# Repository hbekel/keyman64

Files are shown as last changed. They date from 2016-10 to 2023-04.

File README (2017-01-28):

Keyman64

Programmable C64 keyboard interceptor and hardware control system

The keyman64 is a programmable keyboard interceptor and hardware
control system for computers equipped with a simple 64-key matrix
keyboard.

It is installed between the keyboard and the computer, continually
scanning the keyboard matrix and relaying the keyboard state to the
computer using a crosspoint switch. To the computer, the crosspoint
switch matrix looks just like a physical keyboard, while the keyman64
gains the ability to intercept keystrokes and control the matrix seen
by the computer.

The keyman64 can be configured to intercept special key combinations
and invoke arbitrary sequences of commands to alter the state of
sixteen general purpose control lines provided on the board. These
lines can be used to control additional hardware instead of using
physical buttons or switches.

Additional features include the ability to send predefined keyboard
macros or to redefine the keyboard layout. Commands can also be sent
from a remote PC via USB, or send on simple serial wire interface,
allowing remote control from either a PC or another microcontroller or
similar device.

For some concrete examples of what the keyman64 can do, see the

http://www.henning-bekel.de/keyman64/#configuration-examples

Please refer to the project page http://www.henning-bekel.de/keyman64
for detailed documentation.

Copyright 2016 Henning Bekel <h.bekel@googlemail.com>

LICENSING

Hardware licenced under CERN OHL v.1.2, see ./hardware/LICENSE.txt
Software and firmware licenced under GNU GPLv3, see ./LICENSE

The software contains MIT licensed code from
https://github.com/arkku/ihex for reading Intel HEX files, Copyright
(c) 2013-2015 Kimmo Kulovesi, see ./intelhex/LICENSE

The firmware contains the V-USB Driver (https://www.obdev.at/vusb),
(C)2008 Objective Development GmbH.

Distributed in the ./bootloader directory is the USBasp bootloader,
(C)2013 Stephan Baerwolf (matrixstorm@gmx.de) and (C)2008 Objective
Development GmbH (https://www.obdev.at/vusb).

In compliance with the terms of the (identical) V-USB driver and
USBasp bootloader licenses (./firmware/usbdrv/License.txt and
./bootloader/License.txt), the entire project is published under

http://www.henning-bekel.de/keyman64

In addition, this distribution contains

- a circuit diagram in PDF format, see ./hardware/keyman64-schematics.pdf
- the full source code for the host software in ./firmware
- this README file
- references to https://www.obdev.at/vusb

The USB Product and Vendor IDs for the Keyman64 USB device have kindly
been provided by OpenMoko, Inc (http://openmoko.org).

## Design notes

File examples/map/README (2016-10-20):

These files demonstrate how to put a simple loader program before an
actual game in order to configure the mappings between additional
buttons connected to the keyman's control lines and the keys that
should be pressed when these button lines go low.

To build this example, make sure that the utilities petcat and c1541
that came with vice are on the path, then type make. This will create
disk.d64 containing a loader program and a game program.

The loader program first configures the keyman by sending the map
commands via the serial interface connected to the processors IO port,
as described on the "serial interface" section on the website.  In
this example, four additional buttons are connected to port b bits 1-4
and mapped to press the a, b, c or d keys.

The file main.asm contains the ml code necessary to send the map
commands over the serial interface. The code is contained in data
lines in loader.bas.

After configuring the keyman, the loader loads the file "game" and
runs it. The "game" is just a simple basic program scanning for and
reporting keypresses for the mapped keys.

How is this useful?

I'm currently testing a small internal board that will allow the
rerouting of the analog lines from the control ports. These lines are
usually connected to the SID and used to read mice or paddles. You can
control the board to either route these lines to the SID as usual, or
you can route them "somewhere else" instead. And this will allow using
joysticks with two additional buttons connected to the paddle lines
and routed to the keyman, where the button presses can be mapped to
key presses.

For example, you could play games like Turrican and configure the
additional button tp press space in order to detonate your bombs, or
ready and fire missiles in Elite using the joystick, where the buttons
can be mapped to the t and m keys.

Since the keymans mappings can be reconfigured by a program running on
the C64 via the serial interface, it becomes trivial to add the proper
configuration to existing games, either by using a simple loader like
the one in this example, or by linking some additional code in front
of it.

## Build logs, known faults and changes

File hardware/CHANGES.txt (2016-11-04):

Add detailed descriptions of modifications made to the original
documentation in this file.

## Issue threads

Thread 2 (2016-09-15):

Feature Request: Grouping individual control lines

c0zmo, 2016-09-15:
Grouping individual control lines

In the current software, consecutive control lines can be tempered with as a n-bit-value using commands like 'increment port a bits 0-3' or 'clear port b bits 6-7'. However, there are situations where it would be very useful if individual lines on both ports could be grouped together to perform as above, i.e. when using a ribbon cable to connect the control lines. My suggestion is the implementation of a 'GROUP' command.

Examples:
GROUP RepromCharset=port a bit 0, port b bit 0
GROUP RepromKernal=port a bit 1, port b bit 1
GROUP MixSID=port a bit 6, port a bit 7

Now the Charset and Kernal could be changed with:
C: INCREASE RepromCharset
K: INCREASE RepromKernal

hbekel, 2016-09-15:
As for the suggestion itself, this will require some work under hood, since neither the configuration format nor the code dealing with bit ranges is prepared for this. I will have to look into it.

However, I don't think a dedicated GROUP directive is required, since the same can be achieved with user defined symbols, as in

```
RepromCharset = port a bit 0, port b bit 0

C: increase RepromCharset
```

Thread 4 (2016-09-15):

Feature Request: Configuration Terminal

c0zmo, 2016-09-15:
Configuration Terminal

Let the Keyman64 be programmable from the C64 alone by implementing a console-like command interface that uses the BASIC prompt as a terminal.

You could list the current confuration, alter control lines directly or even program new macros.

Mock-Up example:

READY.      <meta+F7> issues 'CONSOLE'-command
KEYMAN64 VERSION x.x BY HENNING
TYPE '?' FOR HELP.
> SHOW CONFIG <RETURN>
C: INCREASE PORT A BITS 0-1
K: INCREASE PORT A BITS 2-3
R: EXEC $FA

$FA: CLEAR PORT B BIT 7
$FA: SLEEP 20
$FA: TRISTATE PORT B BIT 7

> SHOW PORTS
    0 1 2 3 4 5 6 7
A: C C T T T T T T
B: T T S T C C C C

> TRISTATE PORT A BIT 0
B: T C T T T T T T

hbekel, 2016-09-15:
I like the idea of a shell, and I have been thinking about that, too. However, being able to enter plain text commands using the same syntax as in the configuration file would mean having to move the parser code into the Atmel as well. Not sure if that will be practical or whether it will still fit. Do you have any practical use cases for this?

And listing the current configuration in plain text would mean to also move the code that converts back from binary to configuration file syntax to the Atmel.

While this would probably be a neat feature, I'm not convinced that it justifies the effort.

c0zmo, 2016-09-15:
Well, the practical use would be independecy of a PC to check the config or perform changes :) However, you could start with a more or less "raw" dump of the config and the possibility to directly manipulate single control lines like in my example above.

Ultimately, I believe this would put Keyman64 onto a new level. Just consider how feasible it is just to install the proper USB-drivers under Windows. :(

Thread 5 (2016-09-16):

5V Power Connector for supplying other hardware

c0zmo, 2016-09-16:
What do you think about a power connector where one can drive i.e. the Overlay64 without having to draw power from the motherboard? It could be placed next to the serial interface and the USB socket.

hbekel, 2016-09-20:
Yes, that's a good idea. I'll might as well add a few while I'm at it if I find enough space.

hbekel, 2017-04-26:
It turns out this is a bad idea after all, especially when trying to supply power and ground to the Overlay64 from the keyman64 and when also using a long cable from the mainboard keyboard connector to the keyman64. The cable will create a long ground return path which lifts the ground at the Overlay in relation to the video signal and will prevent the overlay's LM1881 from properly detecting sync, especially with dark screen contents. The overlay's GND should be connected as close as possible to the video signal output.

Thus, no other device should probably be powered from the keyman just because "it's there already".

Closed 2017-04-26.

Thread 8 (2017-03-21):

Power-On-Keypress-Detection

c0zmo, 2017-03-21:
When a definable key is held down while powering up the unit, an alternative init-config is executed instead of (or following the) default one at the beginning of the config. The user could select which Kernal to use, mount a certain disk-image on the 1541U etc.

hbekel, 2017-04-19:
I think it will be easier and cleaner to implement a certain key to execute a command sequence bound to a non-key-slot instead of using different startup sections. I will look into this, thanks for the suggestion :)

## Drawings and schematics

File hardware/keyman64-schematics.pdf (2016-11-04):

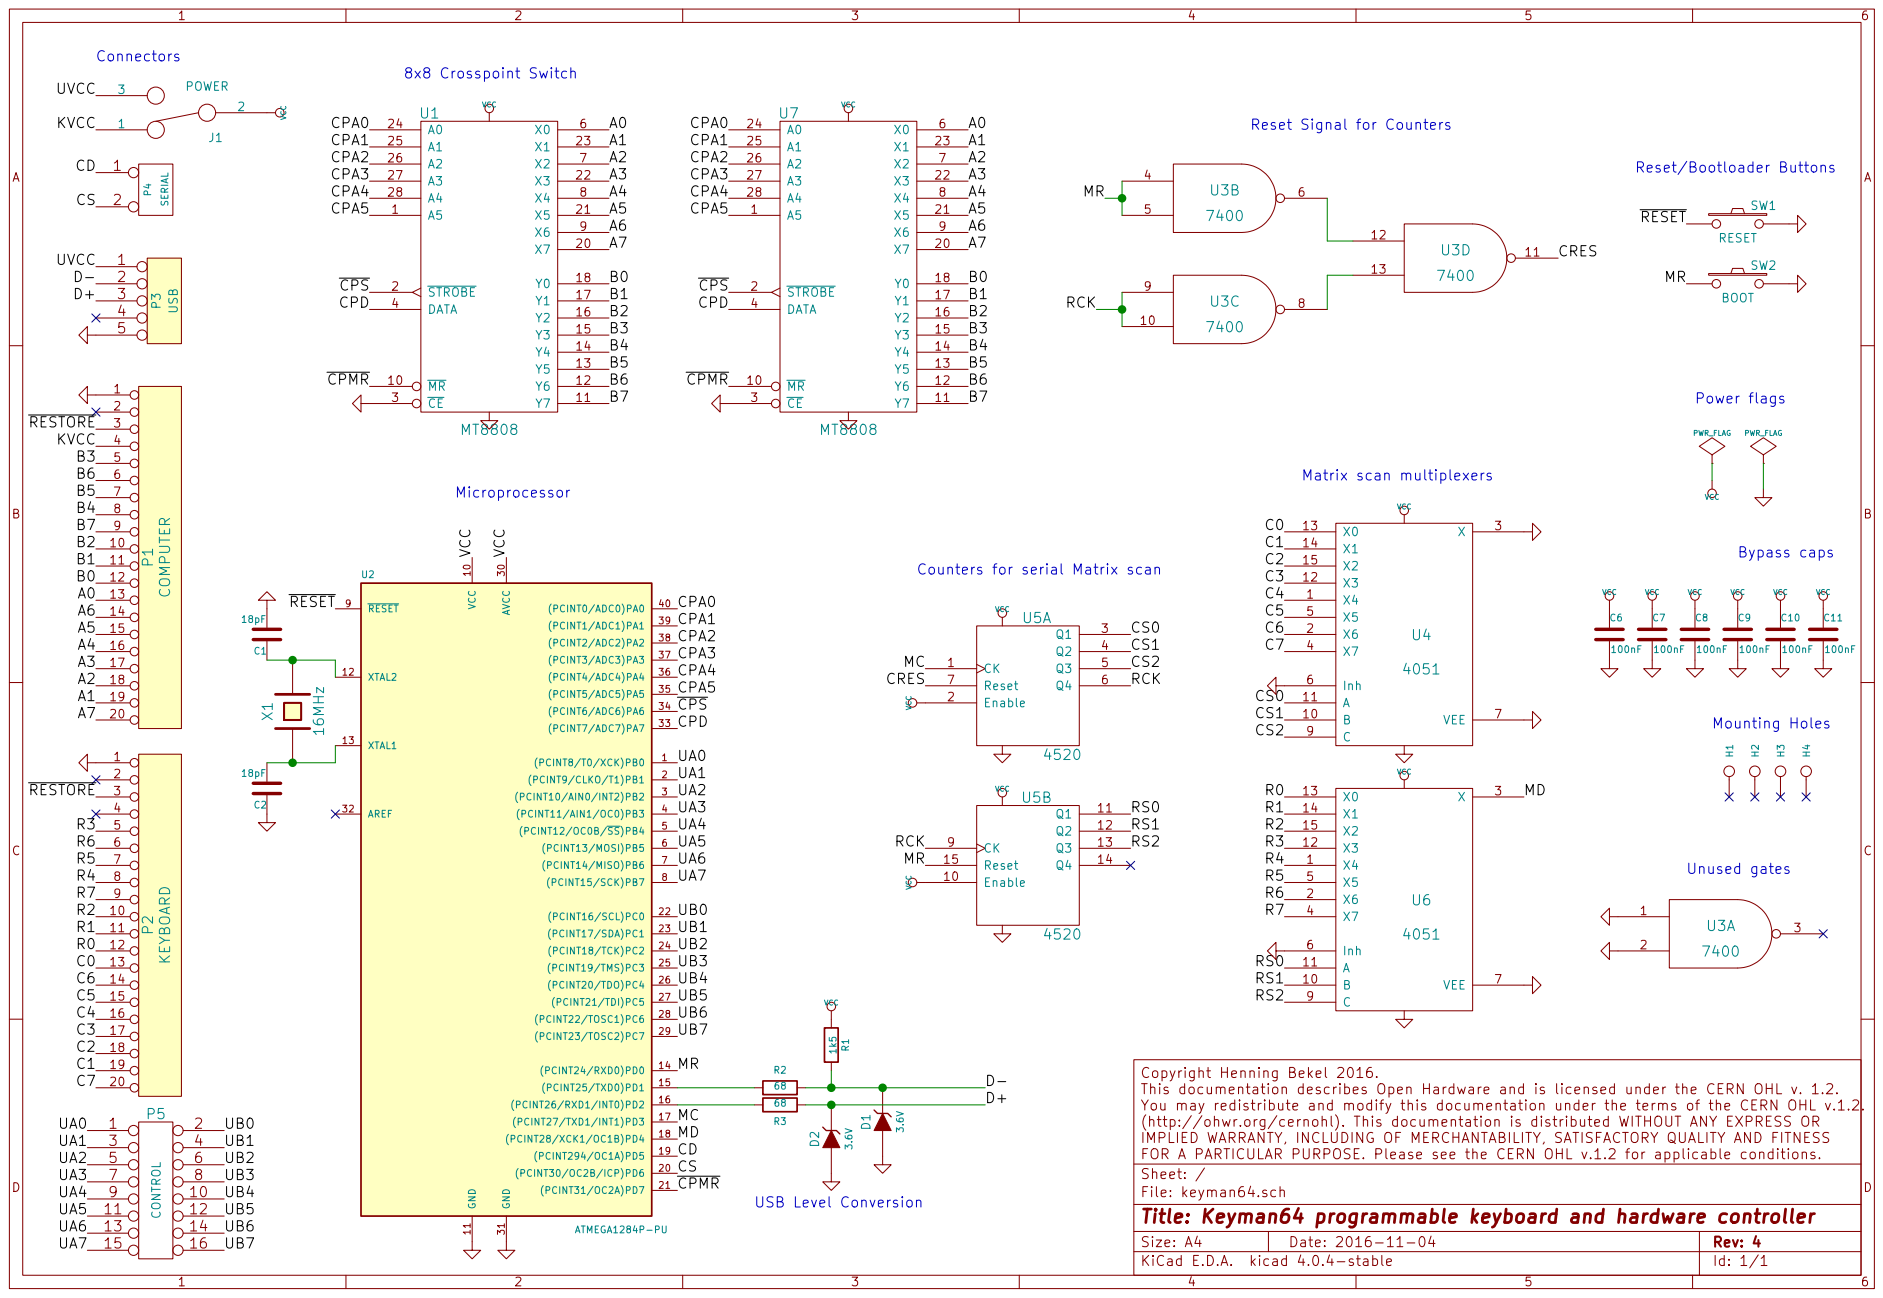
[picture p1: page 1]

Reset Signal for Counters

Bypass caps VCC VCC
Counters for serial Matrix scan

VCC USB Level Conversion

Id: 1/1 Title: Keyman64 programmable keyboard and hardware controller

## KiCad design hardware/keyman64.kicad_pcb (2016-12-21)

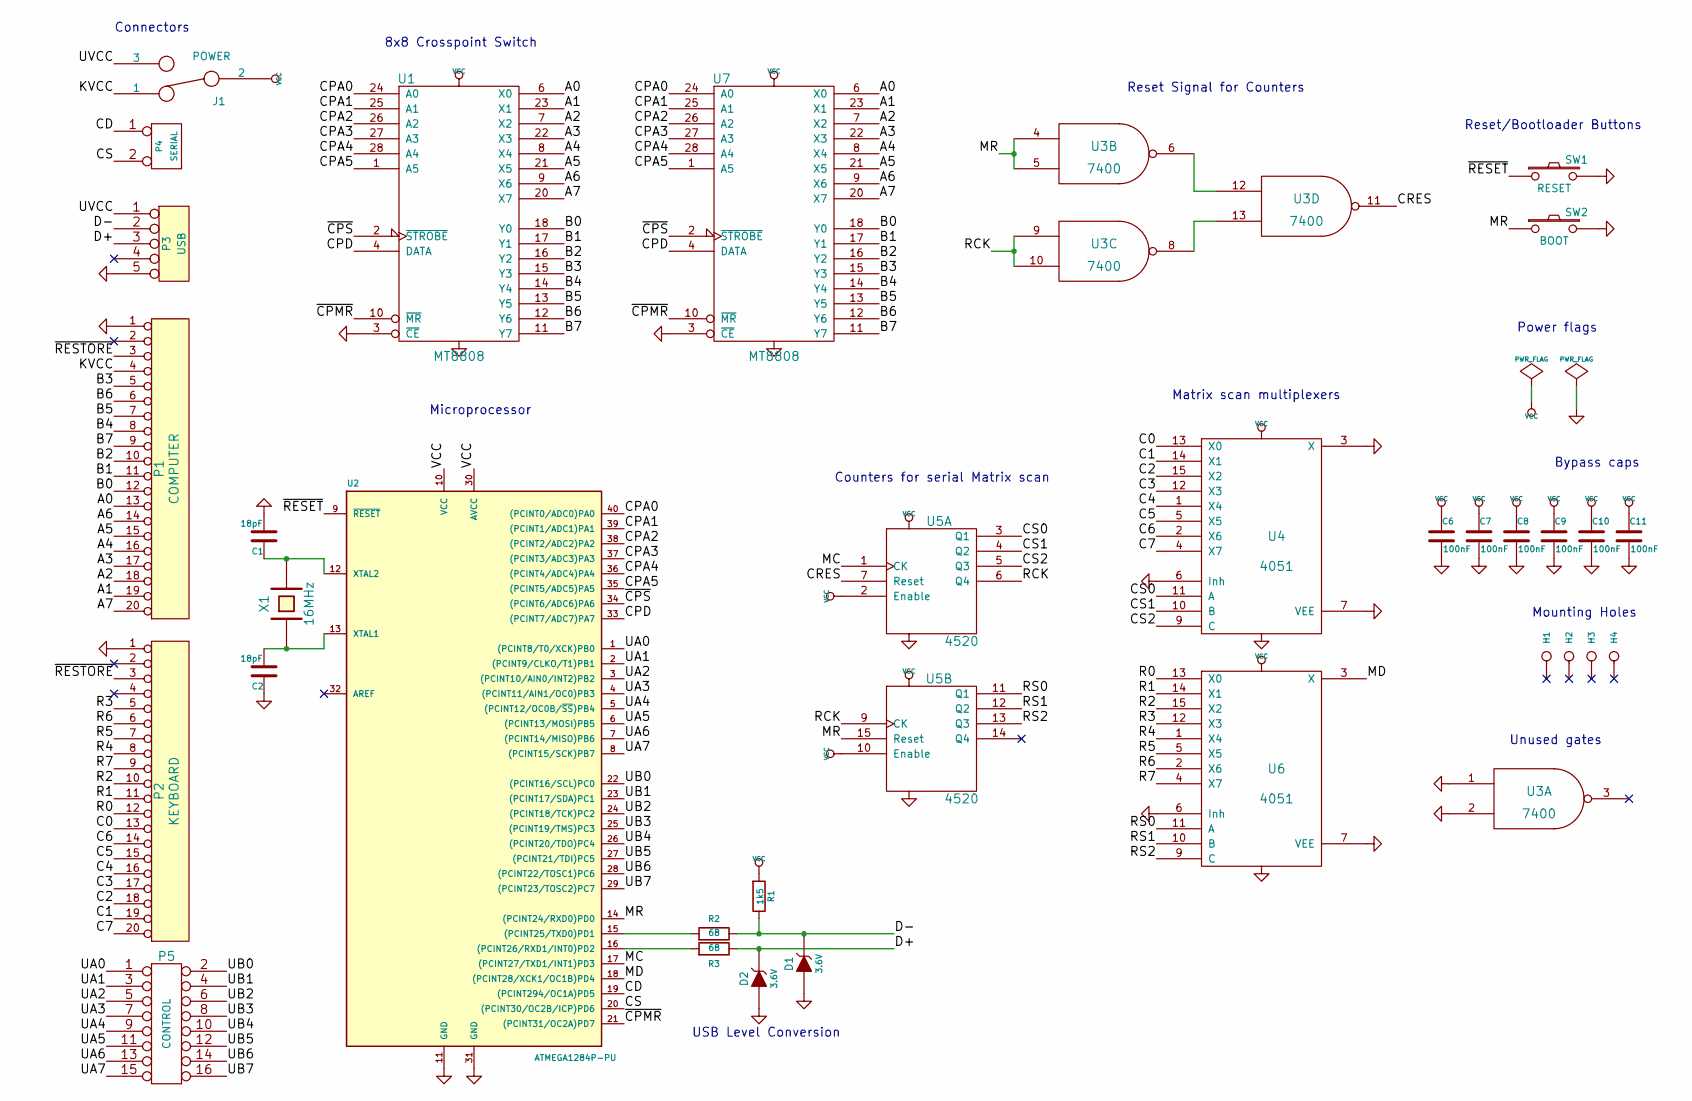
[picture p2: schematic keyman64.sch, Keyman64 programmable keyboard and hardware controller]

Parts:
C1, C2: 18pF; C_Disc_D3_P2.5
C6, C7, C8, C9, C10, C11: 100nF; C_Disc_D3_P2.5
D1, D2: 3.6V; D3
H1, H2, H3, H4: CONN_1; MountingHole_4mm
J1: POWER; pinHeader-3x1
P1: COMPUTER; pinHeader-20x1
P2: KEYBOARD; pinHeader-20x1
P3: USB; USB-MINI-B-H
P4: SERIAL; pinHeader-2x1
P5: CONTROL; pin_array_8x2
R1: 1k5; R3
R2, R3: 68; R3
SW1: RESET; Button
SW2: BOOT; Button
U1: MT8808; DIP-28__600
U2: ATMEGA1284P-PU; DIP-40__600
U3: 7400; DIP-14__300
U4, U6: 4051; DIP-16__300
U5: 4520; DIP-16__300
U7: MT8808; PLCC28
X1: 16MHz; HC-49V

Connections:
/A0: P1.13, U1.6 (X0), U7.6 (X0)
/A1: P1.19, U1.23 (X1), U7.23 (X1)
/A2: P1.18, U1.7 (X2), U7.7 (X2)
/A3: P1.17, U1.22 (X3), U7.22 (X3)
/A4: P1.16, U1.8 (X4), U7.8 (X4)
/A5: P1.15, U1.21 (X5), U7.21 (X5)
/A6: P1.14, U1.9 (X6), U7.9 (X6)
/A7: P1.20, U1.20 (X7), U7.20 (X7)
/B0: P1.12, U1.18 (Y0), U7.18 (Y0)
/B1: P1.11, U1.17 (Y1), U7.17 (Y1)
/B2: P1.10, U1.16 (Y2), U7.16 (Y2)
/B3: P1.5, U1.15 (Y3), U7.15 (Y3)
/B4: P1.8, U1.14 (Y4), U7.14 (Y4)
/B5: P1.7, U1.13 (Y5), U7.13 (Y5)
/B6: P1.6, U1.12 (Y6), U7.12 (Y6)
/B7: P1.9, U1.11 (Y7), U7.11 (Y7)
/C0: P2.13, U4.13 (X0)
/C1: P2.19, U4.14 (X1)
/C2: P2.18, U4.15 (X2)
/C3: P2.17, U4.12 (X3)
/C4: P2.16, U4.1 (X4)
/C5: P2.15, U4.5 (X5)
/C6: P2.14, U4.2 (X6)
/C7: P2.20, U4.4 (X7)
/CD: P4.1, U2.19 ((PCINT294/OC1A)PD5)
/CPA0: U1.24 (A0), U2.40 ((PCINT0/ADC0)PA0), U7.24 (A0)
/CPA1: U1.25 (A1), U2.39 ((PCINT1/ADC1)PA1), U7.25 (A1)
/CPA2: U1.26 (A2), U2.38 ((PCINT2/ADC2)PA2), U7.26 (A2)
/CPA3: U1.27 (A3), U2.37 ((PCINT3/ADC3)PA3), U7.27 (A3)
/CPA4: U1.28 (A4), U2.36 ((PCINT4/ADC4)PA4), U7.28 (A4)
/CPA5: U1.1 (A5), U2.35 ((PCINT5/ADC5)PA5), U7.1 (A5)
/CPD: U1.4 (DATA), U2.33 ((PCINT7/ADC7)PA7), U7.4 (DATA)
/CRES: U3.11, U5.7 (Reset)
/CS: P4.2 (PM), U2.20 ((PCINT30/OC2B/ICP)PD6)
/CS0: U4.11 (A), U5.3 (Q1)
/CS1: U4.10 (B), U5.4 (Q2)
/CS2: U4.9 (C), U5.5 (Q3)
/D+: D2.1 (K), P3.3, R3.1
/D-: D1.1 (K), P3.2, R1.1, R2.1
/KVCC: J1.1, P1.4
/MC: U2.17 ((PCINT27/TXD1/INT1)PD3), U5.1 (CK)
/MD: U2.18 ((PCINT28/XCK1/OC1B)PD4), U6.3 (X)
/MR: SW2.1, U2.14 ((PCINT24/RXD0)PD0), U3.4, U3.5, U5.15 (Reset)
/R0: P2.12, U6.13 (X0)
/R1: P2.11, U6.14 (X1)
/R2: P2.10, U6.15 (X2)
/R3: P2.5, U6.12 (X3)
/R4: P2.8, U6.1 (X4)
/R5: P2.7, U6.5 (X5)
/R6: P2.6, U6.2 (X6)
/R7: P2.9, U6.4 (X7)
/RCK: U3.9, U3.10, U5.6 (Q4), U5.9 (CK)
/RS0: U5.11 (Q1), U6.11 (A)
/RS1: U5.12 (Q2), U6.10 (B)
/RS2: U5.13 (Q3), U6.9 (C)
/UA0: P5.1, U2.1 ((PCINT8/T0/XCK)PB0)
/UA1: P5.3, U2.2 ((PCINT9/CLKO/T1)PB1)
/UA2: P5.5, U2.3 ((PCINT10/AIN0/INT2)PB2)
/UA3: P5.7, U2.4 ((PCINT11/AIN1/OC0)PB3)
/UA4: P5.9, U2.5 ((PCINT12/OC0B/~SS~)PB4)
/UA5: P5.11, U2.6 ((PCINT13/MOSI)PB5)
/UA6: P5.13, U2.7 ((PCINT14/MISO)PB6)
/UA7: P5.15, U2.8 ((PCINT15/SCK)PB7)
/UB0: P5.2, U2.22 ((PCINT16/SCL)PC0)
/UB1: P5.4, U2.23 ((PCINT17/SDA)PC1)
/UB2: P5.6, U2.24 ((PCINT18/TCK)PC2)
/UB3: P5.8, U2.25 ((PCINT19/TMS)PC3)
/UB4: P5.10, U2.26 ((PCINT20/TDO)PC4)
/UB5: P5.12, U2.27 ((PCINT21/TDI)PC5)
/UB6: P5.14, U2.28 ((PCINT22/TOSC1)PC6)
/UB7: P5.16, U2.29 ((PCINT23/TOSC2)PC7)
/UVCC: J1.3, P3.1
/~CPMR: U1.10 (~MR), U2.21 ((PCINT31/OC2A)PD7), U7.10 (~MR)
/~CPS: U1.2 (~STROBE), U2.34 ((PCINT6/ADC6)PA6), U7.2 (~STROBE)
/~RESET: SW1.1, U2.9 (~RESET)
/~RESTORE: P1.3, P2.3
GND: C1.2, C2.1, C6.2, C7.2, C8.2, C9.2, C10.2, C11.2, D1.2 (A), D2.2 (A), P1.1, P2.1, P3.5, SW1.2, SW2.2, U1.3 (~CE), U1.5 (VSS), U2.11 (GND), U2.31 (GND), U3.1, U3.2, U3.7 (GND), U4.3 (X), U4.6 (Inh), U4.7 (VEE), U4.8 (VSS), U5.8 (VSS), U6.6 (Inh), U6.7 (VEE), U6.8 (VSS), U7.3 (~CE), U7.5 (VSS)
unnamed: C1.1, U2.12 (XTAL2), X1.2
unnamed: C2.2, U2.13 (XTAL1), X1.1
unnamed: R2.2, U2.15 ((PCINT25/TXD0)PD1)
unnamed: R3.2, U2.16 ((PCINT26/RXD1/INT0)PD2)
unnamed: U3.6, U3.12
unnamed: U3.8, U3.13
VCC: C6.1, C7.1, C8.1, C9.1, C10.1, C11.1, J1.2, R1.2, U1.19 (VDD), U2.10 (VCC), U2.30 (AVCC), U3.14 (VCC), U4.16 (VDD), U5.2 (Enable), U5.10 (Enable), U5.16 (VDD), U6.16 (VDD), U7.19 (VDD)

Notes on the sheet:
USB Level Conversion
8x8 Crosspoint Switch
Reset Signal for Counters
Connectors
Counters for serial Matrix scan
Matrix scan multiplexers
Reset/Bootloader Buttons
Microprocessor
Unused gates
Power flags
Bypass caps
Mounting Holes

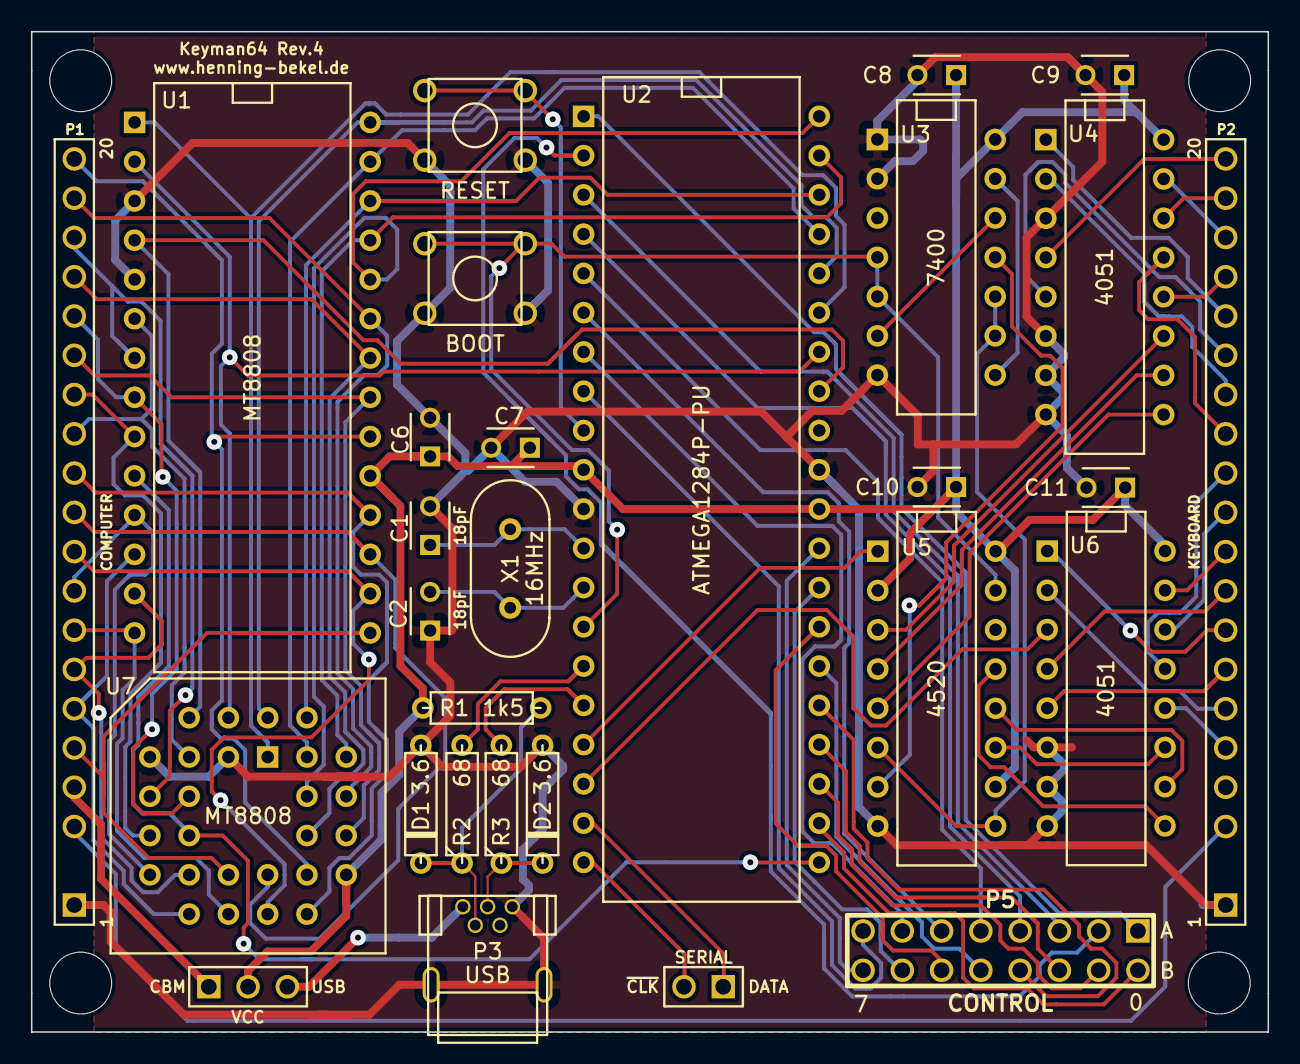
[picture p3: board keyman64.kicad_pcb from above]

Board: 2 copper layers, 80.0 x 64.7 mm, 33 parts (0 on the bottom side), 84 nets.

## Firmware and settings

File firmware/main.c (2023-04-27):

#include <stdint.h>
#include <stdbool.h>
#include <stdio.h>
#include <stdlib.h>
#include <ctype.h>
#include <avr/io.h>
#include <avr/wdt.h>
#include <avr/power.h>
#include <avr/interrupt.h>
#include <avr/eeprom.h>
#include <util/delay.h>

#include "main.h"
#include "encoding.h"
#include "../protocol.h"

uint8_t MC = 1<<PD3; // Matrix Clock
uint8_t MD = 1<<PD4; // Matrix Data
uint8_t MR = 1<<PD0; // Matrix Counter Reset

uint8_t CPS = 1<<PA6; // Crosspoint Strobe
uint8_t CPD = 1<<PA7; // Crosspoint Data
uint8_t CPR = 1<<PD7; // Crosspoint Reset

uint8_t CLK   = 1<<PD6; // Serial Clock (active low)
uint8_t DATA  = 1<<PD5; // Serial Data

#define STATE_RELAY   0x00
#define STATE_COMMAND 0x01
#define STATE_LOCKED  0x02
volatile uint8_t STATE = STATE_RELAY;

#define DEBOUNCE  _delay_ms(20)
#define DELAY     _delay_ms(20)
#define PROPAGATE _delay_ms(1)
#define WITHOUT_DELAY 0

volatile bool matrix[64];
volatile uint8_t locked[64];
volatile uint8_t layout[64];

Storage* storage;
State* transient;

volatile Serial serial;
volatile Mapping mappings[16];
volatile Config* config;
volatile uint8_t meta;
volatile bool boot;
volatile bool reset;

static void (*SetupCrosspointSwitch)(void);
static void (*ResetCrosspointSwitch)(void);
static void (*StrobeCrosspointSwitch)(void);
static void (*ClockMatrix)(void);

static volatile uint8_t usbCommand;
static volatile uint16_t usbDataReceived;
static volatile uint16_t usbDataLength;
static volatile uint8_t *usbData;
static volatile uint16_t usbDataPos;
static volatile uint16_t usbDelay;

int usbDescriptorStringSerialNumber[] = {
  USB_STRING_DESCRIPTOR_HEADER(16),
  0, 0, 0, 0, 0, 0, 0, 0,
  0, 0, 0, 0, 0, 0, 0, 0,
};

//-----------------------------------------------------------------------------

#include "config.h"
#include "../config.c"

//-----------------------------------------------------------------------------

void SetSerial(char *serial) {
  int len = strlen(serial);
  len = (len > 16) ? 16 : len;

  usbDescriptorStringSerialNumber[1] = (int) strlen(serial);

  for(uint8_t i=0; i<16; i++) {
    usbDescriptorStringSerialNumber[i+1] = (int) ((i < len) ? serial[i] : 0);
  }
}

//-----------------------------------------------------------------------------

void EnterBootloader(void) {
  storage->bootflag = BOOTLOADER_MAGIC;
  Storage_save_bootflag(storage);
  Reset();
}

void Reset(void) {
  cli();
  wdt_enable(WDTO_250MS);
  for(;;);
}

//-----------------------------------------------------------------------------

void SetupHardware(void) {

  wdt_disable();

  // Crosspoint Control
  DDRA  = 0b11111111;
  PORTA = 0b11000000;

  // USB, Bootloader, Matrix, Serial interface
  DDRD  = 0b10001001;
  PORTD = 0b11110000;

  SetupSerial();
}

//-----------------------------------------------------------------------------

void SetupSerial(void) {
  ResetSerial();

  PCMSK3 = CLK;
  PCICR |= (1<<PCIE3);
  sei();
}

//-----------------------------------------------------------------------------

void ResetSerial(void) {
  ExpectNextSerialByte();
  serial.command      = 0;
  serial.arguments[0] = 0;
  serial.arguments[1] = 0;
  serial.index        = 0;
}

//-----------------------------------------------------------------------------

void ExpectNextSerialByte() {
  serial.bit  = 1;
  serial.byte = 0;
}

//-----------------------------------------------------------------------------

void ExecuteSerialCommand() {

  uint8_t port;
  uint8_t mask;
  uint8_t key;
  Command *command;

  switch(serial.command) {

  case SERIAL_COMMAND_EXECUTE:
    ExecuteKey(serial.arguments[0]);
    break;

  case SERIAL_COMMAND_KEY_DOWN:
    SetCrosspointSwitchLocked(serial.arguments[0], true, LOCK_SERIAL);
    PROPAGATE;
    break;

  case SERIAL_COMMAND_KEY_UP:
    SetCrosspointSwitchLocked(serial.arguments[0], false, LOCK_SERIAL);
    PROPAGATE;
    break;

  case SERIAL_COMMAND_KEY_PRESS:
    RelayKeyPress(serial.arguments[0]);
    break;

  case SERIAL_COMMAND_MAP:

    port = ((serial.arguments[1] & 0x8) == 0) ? 0 : 1;
    mask = 1<<(serial.arguments[1] & 0x7);
    key = serial.arguments[0];

    Map(port, mask, key);

  case SERIAL_COMMAND_SET:
    command = Command_new();
    command->port = serial.arguments[1] >> 3;
    command->mask = 1<<(serial.arguments[1] & 0x07);
    command->data = serial.arguments[0];

    switch(command->data) {
    case 0 : command->action = ACTION_CLEAR;    break;
    case 1 : command->action = ACTION_SET;      break;
    case 2 : command->action = ACTION_TRISTATE; break;
    default: command->action = ACTION_NONE;     break;
    }

    ExecuteCommand(config, command);
    break;

  case SERIAL_COMMAND_TYPE:
    chrout(serial.arguments[0]);
    break;
  }
}

//-----------------------------------------------------------------------------

ISR(PCINT3_vect) {

  if((PIND & CLK) != 0) return;

  if((PIND & DATA) != 0) {
    serial.byte |= serial.bit;
  }
  serial.bit = serial.bit << 1;

  if(serial.bit == 0) { // byte complete

    if(serial.index == 0) { // received command
      serial.command = serial.byte;
      serial.index = SERIAL_COMMAND_ARITY_FOR[serial.command];
    }
    else { // received argument
      serial.arguments[--serial.index] = serial.byte;
    }

    if(serial.index == 0) { // all arguments received
      ExecuteSerialCommand();
      ResetSerial();
    }
    else {
      ExpectNextSerialByte();
    }
  }
}

//-----------------------------------------------------------------------------

void SetupMappings(void) {
  for(uint8_t i=0; i<16; i++) {
    mappings[i].pins = NULL;
  }
}

//-----------------------------------------------------------------------------

static uint8_t mask2bitnum(uint8_t mask) {
  for(uint8_t i = 0; i<8; i++) {
    if(mask & (1<<i)) return i;
  }
  return 0;
}

//-----------------------------------------------------------------------------

void Map(uint8_t p, uint8_t mask, uint8_t key) {

  uint8_t volatile *port = (p == PORT_A) ? &PORTB : &PORTC;
  uint8_t volatile *pins = (p == PORT_A) ? &PINB : &PINC;
  uint8_t volatile *ddr  = (p == PORT_A) ? &DDRB : &DDRC;

  Mapping volatile *mapping = &mappings[mask2bitnum(mask) | (p<<3)];

  mapping->pins = pins;
  mapping->mask = mask;
  mapping->key = key;

  (*ddr) &= ~mask;
  (*port) |= mask;
}

//-----------------------------------------------------------------------------

void ApplyMappings(void) {
  bool closed = false;
  Mapping volatile *mapping;
  uint8_t lock;

  for(uint8_t i=0; i<16; i++) {
    mapping = &mappings[i];
    lock = LOCK_MAP + i;

    if(mapping->pins == NULL) continue;

    closed = ((*mapping->pins) & mapping->mask) == 0;
    if(closed) {
      SetCrosspointSwitchLocked(mapping->key, true, lock);
    }
    else {
      if(locked[mapping->key] == lock) {
        SetCrosspointSwitchLocked(mapping->key, false, lock);
      }
    }
  }
}

//-----------------------------------------------------------------------------

void SetupUSB(void) {

  cli();
  usbInit();

  usbDeviceDisconnect();

  _delay_ms(500);

  usbDeviceConnect();
  sei();

  usbData = NULL;
}

//-----------------------------------------------------------------------------

void SetupKeyboardLayout(void) {
  for(uint8_t i=0; i<64; i++) {
    layout[i] = i;
  }
}

//-----------------------------------------------------------------------------

int ReadEeprom(FILE* file) {

  static volatile uint16_t addr = 0;
  return eeprom_read_byte((uint8_t *) (addr++));
}

//-----------------------------------------------------------------------------

int WriteEeprom(char data, FILE* file) {

  static volatile uint16_t addr = 0;
  eeprom_update_byte((uint8_t*) (addr++), data);
  return 0;
}

//-----------------------------------------------------------------------------

FILE eeprom = FDEV_SETUP_STREAM(WriteEeprom, ReadEeprom, _FDEV_SETUP_RW);

//-----------------------------------------------------------------------------

int ReadUSBData(FILE* file) {
  return usbData[usbDataPos++];
}

//-----------------------------------------------------------------------------

FILE usbdata = FDEV_SETUP_STREAM(NULL, ReadUSBData, _FDEV_SETUP_READ);

//-----------------------------------------------------------------------------

void ExecuteImmediateCommands(volatile Config* cfg, uint16_t delay) {
  uint16_t ms;
  for(int i=0; i<cfg->num_bindings; i++) {
    if(cfg->bindings[i]->key == KEY_IMMEDIATE) {
      for(int k=0; k<cfg->bindings[i]->num_commands; k++) {
        ExecuteCommand(cfg, cfg->bindings[i]->commands[k]);

        if(delay) {
          ms = delay;
          while(ms--) {
            _delay_ms(1);
          }
        }
      }
    }
  }
}

//-----------------------------------------------------------------------------

void DisableJTAG(void) {
  MCUCR |= (1<<JTD);
  MCUCR |= (1<<JTD);
}

//-----------------------------------------------------------------------------

void ResetCounter(void) {
  PORTD |= MR;
  PORTD &= ~MR;
}

//-----------------------------------------------------------------------------

void ClockMatrixFast(void) {
  PORTD |= MC;
  _delay_us(5);
  PORTD &= ~MC;
}

//-----------------------------------------------------------------------------

void ClockMatrixSlow(void) {
  PORTD |= MC;
  _delay_us(50);
  PORTD &= ~MC;
}

//-----------------------------------------------------------------------------

bool ScanMatrix(void) {
  bool keyDown = false;
  uint8_t row = 0;
  uint8_t col = 0;

  ResetCounter();

  for(row=0; row<8; row++) {
    for(col=0; col<8; col++) {
      if((PIND & MD) == 0) {
        matrix[row*8+col] = true;
        keyDown = true;
      }
      else {
        matrix[row*8+col] = false;
      }
      ClockMatrix();
    }
  }
  return keyDown;
}

//-----------------------------------------------------------------------------

void SetupCrosspointSwitch22106(void) {
  PORTD |= CPR;
}

void SetupCrosspointSwitch8808(void) {
  PORTD &= ~CPR;
}

//-----------------------------------------------------------------------------

void ResetCrosspointSwitch22106(void) {
  for(uint8_t i=0; i<64; i++) SetCrosspointSwitch(i, false);
}

void ResetCrosspointSwitch8808(void) {
  for(uint8_t i=0; i<64; i++) SetCrosspointSwitch(i, false);
}

//-----------------------------------------------------------------------------

void StrobeCrosspointSwitch22106(void) {
  PORTA &= ~CPS;
  PORTA |= CPS;
}

void StrobeCrosspointSwitch8808(void) {
  PORTA |= CPS;
  PORTA &= ~CPS;
}

//-----------------------------------------------------------------------------

void SetCrosspointSwitch(uint8_t index, bool closed) {
  if(locked[index]) return;

  index = closed ? (index | CPD) : (index & ~CPD);
  index |= CPS;
  PORTA = index;

  StrobeCrosspointSwitch();
}

//-----------------------------------------------------------------------------

void SetCrosspointSwitchLocked(uint8_t index, bool closed, uint8_t lock) {
  if(locked[index] && locked[index] != lock) return;

  if(!locked[index]) SetCrosspointSwitch(index, closed);
  locked[index] = closed ? lock : LOCK_NONE;
  if(!locked[index]) SetCrosspointSwitch(index, closed);
}

//-----------------------------------------------------------------------------

void RelayMatrix(void) {
  for(uint8_t i=0; i<64; i++) {
    SetCrosspointSwitch(layout[i], matrix[i]);
  }
}

//-----------------------------------------------------------------------------

void RelayKeyPress(volatile uint8_t key) {
  SetCrosspointSwitch(key, true);
  DELAY;
  SetCrosspointSwitch(key, false);
}

//-----------------------------------------------------------------------------

bool IsKeyDown(volatile uint8_t key) {
  return matrix[key];
}

//-----------------------------------------------------------------------------

bool IsKeyUp(volatile uint8_t key) {
  return !matrix[key];
}

//-----------------------------------------------------------------------------

bool IsKey(volatile uint8_t key) {
  return key < 64;
}

//-----------------------------------------------------------------------------

bool QueryKeyDown(volatile uint8_t key) {
  if(!IsKey(key)) return false;

  bool result = false;

  if(ScanMatrix() && IsKeyDown(key)) {
    DEBOUNCE;
    result = ScanMatrix() && IsKeyDown(key);
  }
  return result;
}

//-----------------------------------------------------------------------------

bool QueryKeyUp(volatile uint8_t key) {
  if(!IsKey(key)) return false;

  bool result = false;

  ScanMatrix();

  if(IsKeyUp(key)) {
    DEBOUNCE;
    ScanMatrix();

    result = IsKeyUp(key);
  }
  return result;
}

//-----------------------------------------------------------------------------

void chrout(char chr) {
  Sequence *sequence;
  uint8_t code;
  uint8_t key;
  static uint8_t last;

  sequence = &(encoding[(uint8_t)chr]);

  for(uint16_t k=0; k<sequence->size; k++) {
    code = sequence->codes[k];

    if((code & CODE_MASK) == CODE_KEY_DOWN) {
      SetCrosspointSwitch(code & ~CODE_MASK, true);
      PROPAGATE;
    }
    else if((code & CODE_MASK) == CODE_KEY_UP) {
      SetCrosspointSwitch(code & ~CODE_MASK, false);
      PROPAGATE;
    }
    else if((code & CODE_MASK) == CODE_KEY_PRESS) {
      key = (code & ~CODE_MASK);

      if(key == last) DELAY;

      RelayKeyPress(key);
      last = key;
    }
  }
}

//-----------------------------------------------------------------------------

static FILE direct_mode_stdout = FDEV_SETUP_STREAM(chrout, NULL, _FDEV_SETUP_WRITE);

//-----------------------------------------------------------------------------

void SetupStdout(void) {
  stdout = &direct_mode_stdout;
}

//-----------------------------------------------------------------------------

void ExecuteKey(uint8_t key) {
  Binding *binding;

  for(int i=0; i<config->num_bindings; i++) {
    binding = config->bindings[i];

    if(key == binding->key) {
      ExecuteBinding(binding);
    }
  }
}

//-----------------------------------------------------------------------------

void ExecuteBindingInteractively(Binding *binding) {

  if(binding->count > 0) {
    if(--(binding->count) == 0) {
      ExecuteBinding(binding);
      Binding_reset(binding);
    }
  }
}

//-----------------------------------------------------------------------------

void ExecuteBinding(Binding* binding) {
  Command *command;

  for(int i=0; i<binding->num_commands; i++) {
    command = binding->commands[i];

    if((command->policy == POLICY_ALWAYS) ||
       (command->policy == POLICY_EVEN && binding->state == STATE_EVEN) ||
       (command->policy == POLICY_ODD  && binding->state == STATE_ODD)) {

      ExecuteCommand(config, command);
    }
  }
  binding->state = (binding->state == STATE_EVEN) ? STATE_ODD : STATE_EVEN;
}

//-----------------------------------------------------------------------------

void Lock(void) {

  if(strlen(storage->password)) {
    ExecuteKey(KEY_LOCKED);
    STATE = STATE_LOCKED;
  }
  else {
    printf("no password defined\n\n");
  }
}

//-----------------------------------------------------------------------------

void Unlock(void) {
  ExecuteKey(KEY_UNLOCKED);
  STATE = STATE_RELAY;
}

//-----------------------------------------------------------------------------

bool ResolvePort(uint8_t num, uint8_t volatile **port, uint8_t volatile** ddr) {

  *port = NULL;

  if(num <= PORT_B) {
    *port = (num == PORT_A) ? &PORTB : &PORTC;
    *ddr  = (num == PORT_A) ? &DDRB : &DDRC;
  }
  else if(Config_has_expansion(config)) {

    Expansion *expansion = config->expansion;
    num -= 2;

    if(num < expansion->num_ports) {
      *port = &(expansion->ports[num]);
      *ddr  = &(expansion->ddr);
    }
  }
  return *port != NULL;
}

//-----------------------------------------------------------------------------

void ExecuteCommand(volatile Config *cfg, Command* cmd) {
  uint8_t volatile *port;
  uint8_t volatile *ddr;

  uint8_t value;
  uint8_t mask;
  uint8_t offset;
  uint8_t dir;
  uint8_t key;
  uint8_t tmp;
  uint16_t index;
  uint32_t duration;

  if(!ResolvePort(cmd->port, &port, &ddr)) return;

  switch(cmd->action) {

  case ACTION_NONE:
    break;

  case ACTION_DEFINE_META:
    meta = cmd->data;
    break;

  case ACTION_SET:
    offset = 0;
    mask = cmd->mask;

    while((mask & 1) == 0) {
      mask = mask >> 1;
      offset++;
    }

    value = (cmd->data & mask) << offset;

    *port &= ~cmd->mask;
    *port |= value;
    *ddr |= cmd->mask;
    break;

  case ACTION_CLEAR:
    *ddr |= cmd->mask;
    *port &= ~cmd->mask;
    break;

  case ACTION_INVERT:
    value = *port;
    value &= cmd->mask;
    value ^= cmd->mask;

    *ddr |= cmd->mask;
    *port &= ~cmd->mask;
    *port |= value;
    break;

  case ACTION_INCREASE:
  case ACTION_DECREASE:
    mask = cmd->mask;
    value = *port & cmd->mask;
    offset = 0;
    dir = cmd->action == ACTION_INCREASE ? 1 : -1;

    while((mask & 1) == 0) {
      mask = mask >> 1;
      value = value >> 1;
      offset++;
    }
    value += dir;
    value = value & mask;
    value = value << offset;

    *ddr |= cmd->mask;
    *port &= ~cmd->mask;
    *port |= value;
    break;

  case ACTION_TRISTATE:
    *ddr &= ~cmd->mask;
    *port &= ~cmd->mask;
    break;

  case ACTION_SLEEP_SHORT:
    duration = cmd->mask | (cmd->data << 8);
    while(duration--) {
      _delay_ms(1);
    }
    break;

  case ACTION_SLEEP_LONG:
    index = cmd->mask | (cmd->data << 8);
    duration = cfg->longs[index];
    while(duration--) {
      _delay_ms(1);
    }
    break;

  case ACTION_EXEC:
    ExecuteKey(cmd->data);
    break;

  case ACTION_KEY_DOWN:
    SetCrosspointSwitch(cmd->data, true);
    break;

  case ACTION_KEY_UP:
    SetCrosspointSwitch(cmd->data, false);
    break;

  case ACTION_TYPE:
    index = cmd->mask | (cmd->data << 8);
    printf(cfg->strings[index]);
    break;

  case ACTION_BOOT:
    boot = true;
    break;

  case ACTION_SWAP:
    tmp = layout[cmd->mask];
    layout[cmd->mask] = layout[cmd->data];
    layout[cmd->data] = tmp;
    break;

  case ACTION_KEY_PRESS:
    RelayKeyPress(cmd->data);
    break;

  case ACTION_DEFINE_SWITCH:
    if(cmd->data == SWITCH_22106) {
      SetupCrosspointSwitch = &SetupCrosspointSwitch22106;
      ResetCrosspointSwitch = &ResetCrosspointSwitch22106;
      StrobeCrosspointSwitch = &StrobeCrosspointSwitch22106;
    }
    if(cmd->data == SWITCH_8808) {
      SetupCrosspointSwitch = &SetupCrosspointSwitch8808;
      ResetCrosspointSwitch = &ResetCrosspointSwitch8808;
      StrobeCrosspointSwitch = &StrobeCrosspointSwitch8808;
    }
    break;

  case ACTION_DEFINE_SPEED:
    if(cmd->data == SPEED_SLOW) {
      ClockMatrix = &ClockMatrixSlow;
    }
    if(cmd->data == SPEED_FAST) {
      ClockMatrix = &ClockMatrixFast;
    }
    break;

  case ACTION_DEFINE_SERIAL:
    index = cmd->mask | (cmd->data << 8);
    SetSerial(cfg->strings[index]);
    break;

  case ACTION_SAVE_STATE:
    SaveState();
    break;

  case ACTION_RESTORE_STATE:
    RestoreState();
    break;

  case ACTION_MAP:
    Map(cmd->port, cmd->mask, cmd->data);
    break;

  case ACTION_SHOW_VERSION:
    printf("firmware %s\n\n", VERSION);
    break;

  case ACTION_SHOW_STATE:
    ShowState();
    break;

  case ACTION_LOCK:
    Lock();
    break;

  case ACTION_SET_PASSWORD:
    SetPassword();
    break;

  case ACTION_MEMORIZE:
    GetState(transient);
    break;

  case ACTION_RECALL:
    SetState(transient);
    break;
  }

  if(Config_has_expansion(config) && cmd->port > PORT_B) {
    Expansion_update(config->expansion);
  }
}

//-----------------------------------------------------------------------------

static char* p2s(char **dst, uint8_t volatile *port, uint8_t volatile *ddr) {

  uint8_t i=0;

  for(uint8_t bit=0x80; bit; bit>>=1, i++) {

    if((*ddr) & bit) {
      (*dst)[i] = ((*port) & bit) ? '1' : '0';
    }
    else {
      (*dst)[i] = ((*port) & bit) ? '1' : 'x';
    }
  }
  return (*dst);
}

//-----------------------------------------------------------------------------
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
int main(void) {
  SetupHardware();
  SetupKeyboardLayout();
  SetupMappings();
  SetupStdout();

  meta = KEY_BACKARROW;
  boot = false;
  reset = false;

  SetupCrosspointSwitch = &SetupCrosspointSwitch8808;
  ResetCrosspointSwitch = &ResetCrosspointSwitch8808;
  StrobeCrosspointSwitch = &StrobeCrosspointSwitch8808;

  ClockMatrix = &ClockMatrixFast;

  config = Config_new();

  Config_read(config, &eeprom) || Config_install_fallback(config);

  SetupCrosspointSwitch();
  ResetCrosspointSwitch();

  ScanMatrix();
  RelayMatrix();

  SetupExpansion();

  storage = Storage_new();
  Storage_load(storage);

  transient = State_new();
  GetState(transient);

  ExecuteImmediateCommands(config, WITHOUT_DELAY);

  SetupUSB();

  Binding *binding;
  bool relayMetaKey = true;

  while(true) {

    usbPoll();

    if(boot || reset) {
      _delay_ms(250);
      if(boot) EnterBootloader();
      if(reset) Reset();
    }

    ApplyMappings();

    switch(STATE) {

    //========================================

    case STATE_RELAY:

      if(QueryKeyDown(meta)) {
        Config_reset(config);
        relayMetaKey = true;
        STATE = STATE_COMMAND;
      }
      else {
        RelayMatrix();
      }
      break;

    //========================================

    case STATE_COMMAND:

      if(QueryKeyUp(meta)) {
        if(relayMetaKey) {
          RelayKeyPress(meta);
        }
        STATE = STATE_RELAY;
      }
      else {
        for(int i=0; i<config->num_bindings; i++) {
          binding = config->bindings[i];

          if(QueryKeyDown(binding->key)) {

            ExecuteBindingInteractively(binding);

            while(!QueryKeyUp(binding->key));
            relayMetaKey = false;
          }
        }
      }
      break;

    //========================================

    case STATE_LOCKED:
      if(CheckPassword()) {
        Unlock();
      }
      break;
    }
  }
  return 0;
}

//-----------------------------------------------------------------------------

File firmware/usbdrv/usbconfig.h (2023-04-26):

/* Name: usbconfig.h
 * Project: V-USB, virtual USB port for Atmel's(r) AVR(r) microcontrollers
 * Author: Christian Starkjohann
 * Creation Date: 2005-04-01
 * Tabsize: 4
 * Copyright: (c) 2005 by OBJECTIVE DEVELOPMENT Software GmbH
 * License: GNU GPL v2 (see License.txt), GNU GPL v3 or proprietary (CommercialLicense.txt)
 */

#ifndef __usbconfig_h_included__
#define __usbconfig_h_included__

/*
General Description:
This file is an example configuration (with inline documentation) for the USB
driver. It configures V-USB for USB D+ connected to Port D bit 2 (which is
also hardware interrupt 0 on many devices) and USB D- to Port D bit 4. You may
wire the lines to any other port, as long as D+ is also wired to INT0 (or any
other hardware interrupt, as long as it is the highest level interrupt, see
section at the end of this file).
+ To create your own usbconfig.h file, copy this file to your project's
+ firmware source directory) and rename it to "usbconfig.h".
+ Then edit it accordingly.
*/

/* ---------------------------- Hardware Config ---------------------------- */

#define USB_CFG_IOPORTNAME      D
/* This is the port where the USB bus is connected. When you configure it to
 * "B", the registers PORTB, PINB and DDRB will be used.
 */
#define USB_CFG_DMINUS_BIT      1
/* This is the bit number in USB_CFG_IOPORT where the USB D- line is connected.
 * This may be any bit in the port.
 */
#define USB_CFG_DPLUS_BIT       2
/* This is the bit number in USB_CFG_IOPORT where the USB D+ line is connected.
 * This may be any bit in the port. Please note that D+ must also be connected
 * to interrupt pin INT0! [You can also use other interrupts, see section
 * "Optional MCU Description" below, or you can connect D- to the interrupt, as
 * it is required if you use the USB_COUNT_SOF feature. If you use D- for the
 * interrupt, the USB interrupt will also be triggered at Start-Of-Frame
 * markers every millisecond.]
 */
#define USB_CFG_CLOCK_KHZ       (F_CPU/1000)
/* Clock rate of the AVR in kHz. Legal values are 12000, 12800, 15000, 16000,
 * 16500, 18000 and 20000. The 12.8 MHz and 16.5 MHz versions of the code
 * require no crystal, they tolerate +/- 1% deviation from the nominal
 * frequency. All other rates require a precision of 2000 ppm and thus a
 * crystal!
 * Since F_CPU should be defined to your actual clock rate anyway, you should
 * not need to modify this setting.
 */
#define USB_CFG_CHECK_CRC       0
/* Define this to 1 if you want that the driver checks integrity of incoming
 * data packets (CRC checks). CRC checks cost quite a bit of code size and are
 * currently only available for 18 MHz crystal clock. You must choose
 * USB_CFG_CLOCK_KHZ = 18000 if you enable this option.
 */

/* ----------------------- Optional Hardware Config ------------------------ */

/* #define USB_CFG_PULLUP_IOPORTNAME   D */
/* If you connect the 1.5k pullup resistor from D- to a port pin instead of
 * V+, you can connect and disconnect the device from firmware by calling
 * the macros usbDeviceConnect() and usbDeviceDisconnect() (see usbdrv.h).
 * This constant defines the port on which the pullup resistor is connected.
 */
/* #define USB_CFG_PULLUP_BIT          4 */
/* This constant defines the bit number in USB_CFG_PULLUP_IOPORT (defined
 * above) where the 1.5k pullup resistor is connected. See description
 * above for details.
 */

/* --------------------------- Functional Range ---------------------------- */
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

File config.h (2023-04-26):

#ifndef CONFIG_H
#define CONFIG_H

#include <stdio.h>
#include <stdbool.h>

#define ACTION_SET           0
#define ACTION_INVERT        1
#define ACTION_INCREASE      2
#define ACTION_DECREASE      3
#define ACTION_TRISTATE      4
#define ACTION_SLEEP_SHORT   5
#define ACTION_EXEC          6
#define ACTION_CLEAR         7
#define ACTION_NONE          8
#define ACTION_DEFINE_META   9
#define ACTION_KEY_DOWN      10
#define ACTION_KEY_UP        11
#define ACTION_TYPE          12
#define ACTION_BOOT          13
#define ACTION_SWAP          14
#define ACTION_KEY_PRESS     15
#define ACTION_SLEEP_LONG    16
#define ACTION_DEFINE_SWITCH 17
#define ACTION_SAVE_STATE    18
#define ACTION_RESTORE_STATE 19
#define ACTION_REQUIRES      20
#define ACTION_MAP           21
#define ACTION_SHOW_VERSION  22
#define ACTION_SHOW_STATE    23
#define ACTION_LOCK          24
#define ACTION_SET_PASSWORD  25
#define ACTION_MEMORIZE      26
#define ACTION_RECALL        27
#define ACTION_DEFINE_SPEED  28
#define ACTION_EXPAND        29
#define ACTION_DEFINE_SERIAL 30

#define PORT_A    0
#define PORT_B    1
#define PORT_NONE 0xff

#define SWITCH_22106 0
#define SWITCH_8808  1

#define SPEED_SLOW 0
#define SPEED_FAST 1

const uint8_t POLICY_ALWAYS  = 0b00000000;
const uint8_t POLICY_EVEN    = 0b01000000;
const uint8_t POLICY_ODD     = 0b01100000;

const uint8_t STATE_EVEN     = 0b01000000;
const uint8_t STATE_ODD      = 0b01100000;

typedef struct {
  uint8_t action;
  uint8_t port;
  uint8_t mask;
  uint8_t data;
  uint8_t policy;
} Command;

typedef struct {
  uint8_t num_commands;
  uint8_t key;
  uint8_t state;
  uint8_t times;
  uint8_t count;
  Command** commands;
} Binding;

typedef struct {
  uint8_t ddra;
  uint8_t porta;
  uint8_t ddrb;
  uint8_t portb;
  uint8_t ports[24];
} State;

typedef struct {
  uint8_t clock;
  uint8_t data;
  uint8_t latch;
  uint8_t enable;
  uint8_t num_ports;
  uint8_t* ports;
  uint8_t ddr;
} Expansion;

typedef struct {
  uint16_t num_bindings;
  uint16_t num_strings;
  uint16_t num_longs;
  Binding **bindings;
  char **strings;
  uint32_t *longs;
  Expansion *expansion;
} Config;

uint8_t CONFIG_MAGIC[2] = { 0x1c, 0xcf };
uint8_t KEY_EOF       = 0xff;
uint8_t KEY_IMMEDIATE = 0xfe;
uint8_t KEY_STRING    = 0xfd;
uint8_t KEY_LONG      = 0xfc;
uint8_t KEY_EXPANSION = 0xfb;

Config* Config_new(void);
Binding* Config_add_binding(volatile Config *self, Binding* binding);
bool Config_has_binding(volatile Config* self, uint8_t key);
Binding* Config_get_binding(volatile Config* self, uint8_t key);
Binding* Config_get_or_create_binding(volatile Config* self, uint8_t key);
bool Config_has_string(volatile Config *self, char* string, uint16_t *index);
uint16_t Config_add_string(volatile Config *self, char* string);
bool Config_has_long(volatile Config *self, uint32_t value, uint16_t *index);
uint16_t Config_add_long(volatile Config *self, uint32_t value);
Expansion* Config_set_expansion(volatile Config *self, Expansion* expansion);
bool Config_read(volatile Config *self, FILE* in);
bool Config_install_fallback(volatile Config *self);
void Config_reset(volatile Config *self);
bool Config_has_expansion(volatile Config *self);
void Config_free(Config *self);

Binding* Binding_new(void);
void Binding_set_key(Binding* self, uint8_t key);
Command* Binding_add(Binding* self, Command* command);
void Binding_read(Binding *self, FILE* in);
void Binding_reset(Binding *self);
void Binding_free(Binding *self);

Command* Command_new(void);
void Command_read(Command *self, FILE* in);
void Command_free(Command *self);

State* State_new(void);
void State_free(State* self);

Expansion * Expansion_new(void);
void Expansion_set_num_ports(Expansion* self, uint8_t num_ports);
void Expansion_read(Expansion* self, FILE* in);
void Expansion_free(Expansion* self);

#endif // CONFIG_H

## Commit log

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2015-07-22 Implemented matrix scanning, matrix relay does not work yet
    [main.c]
2015-07-22 Hardware: Removed delay RC for counter reset (not needed)
    [interceptor.sch]
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2015-07-25 Hardware: Trigger power-on-reset when pushing reset switch
    [interceptor.sch]
2015-07-26 Firmware: Corrected inital state of usb lines to avoid host errors
    [main.c]
2015-07-26 Firmware: Also use HWBE line as matrix reset line, reset before each scan
    [main.c]
2015-07-26 Also use HWBE line as matrix reset line, reset before each scan
    [interceptor.sch]
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2015-07-27 Grounded crosspoint enable, connected master reset to uC
    Master Reset line is more suitable to make the matrix "float"
    [interceptor.sch]
2015-07-27 Implemented function to reset crosspoint switch using the master reset line
    [main.c]
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2015-07-27 Fixed bug in ResetCrosspointSwitch, fixed line definitions
    For some reason, when using #define SIG 1<<7 then ~SIG != 0x7f.
    Instead use global uint8_t variables.
    [main.c]
2015-07-27 Fixed tristate command, set pin to input *without* pullup
    [main.c]
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2015-07-28 Added functions for key handling and getting bindings by key
    [config.h, main.c]
2015-07-28 Refactored binding execution, added execute command
    [config.h, main.c]
2015-07-28 Fixed serial command interface bug
    [main.c]
2015-07-28 Renamed types to avoid _t suffix reserved by stdlib
    [config.h, main.c]
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2015-07-31 Software/Firmware: Completed functions for handling configuration
    Refactored/Added all neccessary functions to handle configuration data
    types and fixed some bugs along the way.
    read/write binary data
    parse/print config file format
    All functions operate on streams. The firmware only uses the _read functions
    and passes a stream which has been setup to read from eeprom.
    Also added a test target to test converting conf->bin->conf->bin and compare
    the binary results.
    [config.h, main.c]
2015-08-01 Firmware: Fixed bugs involving configuration and RelayMatrix function
    [main.c]
2015-08-01 Hardware: VSS of 7422106 needs to go to ground instead of VEE
    [interceptor.sch]
2015-08-03 Hardware: Fixed Crosspoint switch and usb connector, routed usb traces
    [interceptor.dsn, interceptor.kicad_pcb, interceptor.sch]
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2015-08-04 Hardware: Rerouted/Moved front copper traces around crystal to bottom layer
    This prevents the metallic crystal casing from shorting traces on the
    front layer in case the pcb has been made without solder mask.
    [interceptor.kicad_pcb]
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2015-08-12 Software: Changed meta key to work as a modifier key
    As long as the meta key is held down, the software listens for and
    executes key bindings. The key is relayed on release if no bound key
    was pressed in the meantime.
    This avoids having to press the meta key twice in order to actually
    type it. The only difference to other keys is that the character does
    not appear immediately on key down but on release. This also makes
    issuing successive commands much easier.
    [main.c]
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2015-08-12 Firmware: Fixed bug in QueryKeyUp() function
    [main.c]
2015-08-15 Hardware/Firmware: Swapped Cassette Sense and Data lines
    [keyman64.kicad_pcb, keyman64.sch]
2015-08-15 Firmware: Fixed bug in ExecuteCommand() (missing break)
    [main.c]
2015-08-15 Firmware: Fixed bug in QueryKey*() functions (skip non-key commands)
    [config.h, main.c]
2015-08-17 Hardware: Fixed bug in schematics/pcb (4520 enable to VCC)
    [keyman64.kicad_pcb, keyman64.sch]
2015-08-18 Firmware: Fixed bug in serial interrupt setup
    [main.c]
2015-08-18 Hardware: Removed EXTVCC Jumper, removed copper around edges
    There is no VCC on the keyboard connector, so VCC must be fed from external
    source anyways if the keyboard cable is simply cut in half and the board
    soldered in between.
    The copper/traces around the keyboard/cia connectors have been removed to
    make it easier to simply solder the wires in instead of adding pin headers
    and proper plugs.
    [keyman64.kicad_pcb, keyman64.sch]
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2015-08-30 Firmware: Don't reset crosspoint switch when entering command mode
    This allows pressing a key in addition to invoking a control command,
    i.e. to press run/stop when resetting an AR/RR module.
    [main.c]
2015-08-30 Software: Added simple test program for reverse keyboard scan
    Here Port B is set to output and Port A is set to input, which is the
    reverse of how the kernal keyscan routine usually does it.
    Proves that the 7422106 has truly bidirectional switches (not stated
    explicitly in the datasheet).
    [reverse.asm]
2015-08-30 Software/Firmware: Added KEY_DOWN/UP actions to allow fine grained control
    This allows holding down keys while performing io state changes, e.g. to
    programatically hold run/stop when resetting an AR/RR cartridge, entering
    into direct mode + fastload.
    [config.h, main.c]
2015-09-02 Firmware: Fixed bug in serial setup code (last fix was bogus)
    [main.c]
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2015-09-07 Software/Firmware: Added "swap" command to swap two keys on the keyboard
    For example, this will change the keyboard to QWERTZ layout:
    swap y z
    [config.h, main.c]
2015-09-07 Firmware: Fixed typing routine for repeated strokes of the same key
    Apparently the kernal key scan routine requires at least 20ms between
    successive strokes of the same key, whereas typing a different key needs
    no delay between the release of the first key and the press of the second
    key. In any case the key needs to be held down for 20ms as well in order
    to be scanned correctly.
    [main.c]
2015-09-12 Firmware: Added small delay after holding/releasing keys during typing
    Fixes shifted keys that would sometimes not be typed correctly otherwise
    [main.c]
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2015-09-14 Firmware: Redesigned serial interface, added command nibble
    [main.c]
2015-09-14 Firmware: Fixed bug in serial interface code
    [main.c]
2015-09-14 Firmware: Fixed serial commands for key down and key up
    When a key is held down via the serial interface, it will remain down
    until it is released via the serial interface up command. The respective
    respective key is locked while it is down, meaning the state of the
    physical keyboard key is excluded from being permanently relayed to the
    crosspoint switch matrix facing the C64.
    [main.c]
2015-09-14 Software/Firmware: Fixed parsing/executing "sleep" commands > 255ms
    [main.c]
2015-09-16 Software: Avoid adding identical strings twice to the binary configuaration
    [config.h]
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2015-09-25 Software/Firmware: Allow configuring crosspoint switch model at runtime
    This avoids having to build/ship different versions of the firmware
    for the crosspoint switch IC model in use.
    The configuration command 'using' has been added for this purpose:
    using CD74HC22106
    using MT8808
    The default model is CD74HC22106 to maintain backwards compatibility.
    These ICs are pin compatible but not signal-compatible: STROBE and MR
    are active-low for the 22106 and active-high for the MT8808.
    [config.h, main.c]
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2015-10-14 Hardware: Fixed file permissions
    [keyman64.dsn, keyman64.kicad_pcb, keyman64.sch]
2015-10-16 Hardware: Changed USB connector to mini-usb-b through-hole footprint
    The footprints fit has not been verified yet, it was created based on the
    datasheet for the reichelt part "USB BWM".
    [keyman64.kicad_pcb, keyman64.sch]
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2015-10-17 Hardware: Added option to power device from USB or external source
    This makes it easier to use the device as a standalone keyboard controller,
    i.e. without actually connecting it to a computer.
    The software will support a standalone mode, in which no crosspoint switch
    and consequently no meta key is required. The port used for the crosspoint
    switch control will be made available as an additional user control port.
    [keyman64.kicad_pcb, keyman64.sch]
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2015-10-17 Firmware: Added support for executing bindings via USB
    [main.c]
2015-10-17 Firmware: Fixed port setup for USB
    [main.c]
2015-10-18 Firmware/Software: Redesigned to execute any command via USB
    The device now implements a low speed usb device implementing a remote
    control interface during regular opertion.
    The semantics of the keyman64 commandline utitlity have been changed
    to allow the execution of arbitrary commands passed on the commandline
    or on stdin via USB, e.g.:
    $ keyman64 exec k
    $ keyman64 type 'run~'
    $ rlwrap keyman64
    exec r
    sleep 10s
    type rem back from reset!~
    ^D
    $ rlwrap keyman64
    The existing conversion funtions can still be invoked by using the
    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
    [config.h, main.c]
2015-10-19 Software/Firmware: Tested and fixed remote control features
    [main.c]
2015-10-22 Hardware: Added holes, fixed/completed silkscreen, improved routing
    [keyman64.kicad_pcb]
2015-10-23 Hardware: Added option to use VCC from mainboard keyboard header
    This is in case you want to make a custom cable to connect the keyman64 to
    the C64 mainboard keyboard header, in which case you might want to use
    PIN 4 of the mainboard header to provide VCC.
    [keyman64.kicad_pcb, keyman64.sch]
2015-10-24 Hardware: Increased board height to 6,4cm to make room for mounting holes
    [keyman64.kicad_pcb, keyman64.sch]
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2015-10-28 Hardware: Improved routing, assured ground connections, fixed silkscreen
    [keyman64.kicad_pcb]
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2015-11-04 Hardware: Revision 2
    Updated svg renderings, fixed some more file modes
    [keyman64.kicad_pcb, keyman64.sch]
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2015-11-16 Hardware: Avoid routing across usb socket on the front layer
    [keyman64.kicad_pcb]
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2015-12-11 Version 1.1
    Changes in this version:
    The project is now licensed under GPL2
    Hardware:
    * Updated to Revision 2
    * Increased board height to 6.4mm
    * Added mounting holes (3m)
    * Switched to through-hole mini-b USB connector
    * Added Pin header to choose power source
    * Switched to tantalum type 10uF caps for th 7660
    * Avoided routing on front layer under USB connector
    * Improved silk screen
    * Cleaned up and reassigned component references
    * Added gerber files to distribution
    Software:
    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
2016-01-19 Software: Added --preserve option for convert command
    When the preserve option is used with the convert command, the currently
    saved state of the control lines is fetched from the device via USB and
    is then included in the newly generated binary configuration. This allows
    the saved state to be preserved across reconfigurations.
    If the device cannot be accessed, the state will be initiated to the default
    state (all lines tristated), which is the default behaviour when --preserve
    is not specified. A warning will be issued in this case.
    [main.c]
2016-01-20 Firmware: fixed compiler warnings due to formerly scalar usbMsgPtr type
    [main.c, usbconfig.h]
2016-01-21 Firmware/Software: Allow executing different commands every other time
    It is now possible to specify an execution policy for commands that controls
    whether a command is always executed each time a binding is triggered or
    only every other time (even or odd):
    <key>:[<policy>] <command>
    Where policy is either "0" or "1" for even or odd. If no policy is given,
    the default is to always execute the command (like before). For example:
    D:0 clear port a bit 0
    D:1 tristate port a bit 0
    When you press <meta>-D for the first time, the clear command is executed.
    The second time you press <meta>-D, the tristate command is executed, and
    so on. This makes a single key act more like an actual switch rath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
    [config.h, main.c]
2016-01-21 Firmware/Software: Fixed bugs in policy handling and parsing
    [config.h, main.c]
2016-01-22 Firmware: Refactored to avoid duplicate loops over bindings
    [main.c]
2016-01-22 Makefile: Worked around broken firmware clean target on cygwin
    The clean target of the firmware makefile accidently deletes usbdrvasm.S
    under cygwin due to the case insensitivity of filenames on windows.
2016-02-26 Firmware/Software: Properly named size members in Config and Binding
    [config.h, main.c]
2016-03-16 Hardware: Increased mounting hole size to 4mm
    This was self-adhesive pcb holders like reichelts AHS 4,8 may be used
    [keyman64.kicad_pcb, keyman64.sch]
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2016-07-25 Hardware: Fixed wrong USB level conversion circuit
    [keyman64.kicad_pcb, keyman64.sch]
2016-08-08 Software: Prevent attempts to bind to reserved slots $FC-$FF
    [config.h]
2016-08-15 Hardware: Routed USBVCC to socket on the bottom layer to avoid possible strain
    [keyman64.kicad_pcb]
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2016-08-16 Hardware: Placed resistors and diodes horizontally
    This allows to assemble the board as flat as possible in case there is not
    much height clearance for installation.
    [keyman64.kicad_pcb, keyman64.sch]
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2016-08-16 Hardware: Using correct button footprints, rerouted
    [keyman64.kicad_pcb, keyman64.sch]
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2016-08-24 Version 1.3
    * Updated to board revision 4
    * Fixed wrong USB level conversion circuit
    * Placed resistors and diodes horizontally
    * Fixed wrong button foorprint
    * Removed hole for pin 2 at keyboard/computer connectors
    * Added custom symbol definitions for configuration files
    * Added frequency test to fallback configuration (<meta>-f)
    Notes:
    Upgrades to the software and firmware are not mandatory.
    In order to use custom symbols in configuration files, only the
    client software needs to be updated.
    In order to use the new frequency test in the fallback configuration, only
    the firmware needs to be upgrades.
    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
    [keyman64.kicad_pcb, keyman64.sch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]
2016-09-21 Software/Firmware: Allow requiring multiple key presses before executing binding
    The user can optionally require a key to be pressed multiple times while the
    meta key is held down before the corresponding commands actually executes.
    Useful to prevent accidental invocations of critical commands, like
    accidentally resetting the machine and loosing unsaved changes in an
    editor.
    Example and proposed syntax:
    r: requires 3
    r: clear port a bit 0
    r: sleep 10
    r: tristate port a bit 0
    [config.h, main.c]
2016-09-21 Firmware: Fixed bug in new multiple key press feature
    [main.c]
2016-09-22 Firmware: Finish USB transfer before entering bootloader
    When sending the boot command via USB the transfer
    is completed before acutally entering the bootloader.
    This eliminates the false error message when executing
    keyman64 boot.
    [main.c]
2016-09-24 Firmware: Reset crosspoint switch before running initial commands
    Didn't initialise the crosspoint switch before running initial commands,
    which caused the INST/DEL key to be held down until the initial
    commands were finished. This was only noticeable when the initial
    sequence contained a long running command involving some delays.
    Also it seems that at least the MT8808 needs a manual reset as well.
    Need to investigate, workaround for now.
    [main.c]
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2016-11-04 Firmware: Fixed debug function, removed debug messages
    [main.c]
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2016-11-08 Software: Sanitized PETSCII encoding, proper escape sequences
    The string literal syntax for the "type" command has
    been corrected and completed. It is now possible for
    the keyman to type everything that can be typed on a
    real C64 keyboard.
    The previous scheme of incorrectly using the ascii tilde,
    pipe and backtick for control codes has been removed,
    making this a breaking but necessary change.
    Instead, proper escape sequences have been added that
    encode the ascii control codes return, newline and form
    feed using \r (0x0d => RETURN), \n (0x0a => SHIFT-RETURN)
    and \f (0x0c => SHIFT-CLRHOME).
    In addition, every 8-bit ascii code point now correctly
    encodes the corresponding petscii code point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
    [main.c]
2016-11-08 Software: Fixed exit code when failing to open USB device
2016-11-17 Version 1.4
    Licensing:
    * Hardware is now licensed under CERN OHL v1.2
    * Software and Firmware are now licensed under GNU GPLv3
    * V-USB driver has been properly sublicenced under GPLv3, see
    README.txt for details
    Bootloader:
    * Reconfigured to create a working bootloader again
    * Modified to allow a reset from firmware that does not trigger the
    bootloaderCondition() (using a magic value at the end of Eeprom).
    Software/Firmware:
    * Added "configure" command to the configuration utility, allowing to
    directly convert and flash a configuration file to eeprom via USB,
    without having to use avrdude and without having to enter the
    bootloader beforehand
    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
    [keyman64.kicad_pcb, keyman64.sch]
2016-11-23 Software: Show usage when called w/o arguments, fixed --identify
    When the client is called without arguments or options, show usage
    information instead of reading commands from stdin. Also run the
    pause command on win32 in case the user double clicked on the binary.
    Require explicit "-" argument to force reading commands from stdin.
    Also fixed buggy --identify option (devices were not yet prepared)
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2017-01-23 Firmware: Return accepts password, prevent setting empty password
    When locked, the password is now accepted by pressing return, i.e.
    return is implicitly added to passwords.
    The password command is now cancelled when an empty password
    is entered.
    [main.c]
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2017-01-26 Hardware: Added missing button 3d model and sources
2017-04-13 Firmware: Added early scan and relay step on powerup
    Added an early one-time keyboard scan and relay step
    before entering USB initialisation to allow any
    extension port modules which do an early keyboard scan
    in their reset routine to work properly at powerup.
    E.g. an Action Replay cartridge will enter right
    into direct mode with fastload enabled if C= is held
    during reset or powerup. Without the additional scan,
    the keyboard won't start working fast enough for this
    and the reset routine would not see the keypress.
    Reported by GI-Joe
    [main.c]
2017-04-19 Software: Fixed bug in symbol parsing, added test case
    Any line containing an equals sign was interpreted
    as a symbol definition, which failed for type commands
    containing an equal signs.
    Reported by Sven Arke
2017-04-20 Firmware: Fixed wrong USB vendor name length in usbconfig.h
    [usbconfig.h]
2017-05-03 Firmware: Fixed new serial command "set" (missing execute)
    [main.c]
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2017-07-06 Software: Added short pin syntax as alternative
    It is now possible to use shorter pin specifications in the configuration
    file, consisting of just the port name and bit or bit range. For example,
    instead of the rather verbose "port a bit 7", the short form "a7" can be
    used. Likewise, "b3-5" is equivalent to "port b bits 3-5".
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2017-07-09 Software: Fixed ambiguity between short pin syntax and F-key names
    The recently added short pin syntax created an ambiguity with the
    function key names F1, F3, F5 and F7, which were misinterpreted as
    pin specifications (e.g port f pin 1) for commands meta, down, up,
    press and exec.
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2017-07-23 Firmware: Attempted to fix heisenbug in typing functions
    It seems that vsprintf into a local char* yields strange results,
    bits of other constant strings or data shows up, but only in some
    compilations (e.g. changing code elsewhere yields different garbage
    or none at all).
    Using a static volatile char* to print into seems to fix it, needs
    more testing though.
    [main.c]
2017-07-24 Firmware: Fixed printing, immediate restore, mappings
    Removed the varargs method for printing, which does not seem to
    work reliably on an AVR (see last commit). That was just syntactic
    sugar anyways.
    Fixed immediate restore command on startup (read stored values
    before executing initial commands).
    Fixed wrong assignments into array of mappings for bits > 3, which
    may have caused undefined behaviour.
    [main.c]
2017-07-26 Software/Firmware: Added USB command and option to reset device
    The new --reset option will reset the device and boot the
    application. This can be used to exit the bootloader without
    actually flashing the device.
    Also improved the update procedure.
    [main.c]
2017-07-27 Software/Firmware: Added proper reset command, removed --reset again
    Added proper keyman reset command, removed the --reset option again.
    The "reset" command can be bound to a key, however when invoking
    "keyman64 reset" remotely, the device will still be reset directly
    via USB, regardless of wether the device is in bootloader or
    application mode.
    [config.h, main.c]
2017-07-30 Software/Firmware: Removed device command for reset, kept client command
    It is not really required to be able to bind reset to a key since
    it is only useful to get the device out of bootloader mode, in which
    case keybindings won't work anyways. And it is very likely that users
    are already using a symbol of the same name for their reset sequence,
    thus introducing a command would break existing configurations.
    However, the device can still be reset from the client side using
    the corresponding client command.
    [config.h, main.c]
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2023-04-23 Firmware: Removed unnecessary assertion of crosspoint switch reset line
    Asserting the reset signal of the crosspoint switch does not seem to
    work for all supported models of switches, thus the reset is already
    additinally done in software.
    All that is left to do is initally setup the reset line, i.e. enable the
    crosspoint switch. This has been moved to a new SetupCrosspointSwitch()
    function for clarity.
    In hindsight, driving the reset line from the avr would not have
    been necessary at all if I hadn't decided to add the option of using
    different crosspoint switches (CP22106 and MT8808 only differ on whether
    the control signals are active low or active high).
    I might change this in another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
    [main.c]
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2023-04-26 Software/Firmware: Added command 'serial' to set USB serial number
    A new configuration command 'serial' has been added that allows setting
    the USB serial number string. Maximum length for the string is 16
    characters. If no 'serial' command is issued at startup, the serial number
    defaults to the empty string.
    This allows the user to configure persistent device symlinks for multiple
    keyman64 devices under linux by using appropriate udev rules that take
    the serial number into account.
    The provided basic udev rule has been changed to append the serial number
    string to the device symlink /dev/keyman64 by default. Since the serial
    number defaults to the empty string, the device will still appea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
    [config.h, main.c, usbconfig.h]
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2023-04-27 Firmware: Fixed bug causing loss of saved state when serial set
    A break statement was missing, causing a switch statement to fall
    through from ACTION_DEFINE_SERIAL to ACTION_DEFINE_STATE, which means
    that after a serial was set the saved state would be inadvertedly
    overwritten with the current state.
    [main.c]
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2023-05-05 Fixed errors in device discovery, improved bash completion
    The usb_open() function now properly closes usb devices that were
    opened to get the serial nummer if the requested serial did not match.
    If a specific device requested by serial number was not found, the
    usb_open() function still returned the last keyman64 device that was
    opened to get the serial number. Now it properly returns NULL and prints
    an appropriate error message.
    Bash completion has been improved to complete the --device option,
    offering the serial numbers and device node paths to the connected
    keyman64 devices.

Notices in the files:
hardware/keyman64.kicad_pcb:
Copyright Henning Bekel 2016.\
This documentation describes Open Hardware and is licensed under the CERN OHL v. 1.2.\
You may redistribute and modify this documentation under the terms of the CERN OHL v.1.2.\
